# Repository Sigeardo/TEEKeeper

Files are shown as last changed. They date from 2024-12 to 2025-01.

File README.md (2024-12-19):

<p align="center">
  
</p>

**TEEKeeper** (_Temperature Environment Electronic Keeper_, or _TEEK_ for short) is an open source, Arduino based controller for high temperature electric ovens, such as heat treating ovens for metallurgy/bladesmithing, glass and ceramic kilns, etc.
In a broader sense, this projects aims to develop a platform that can be upgraded, expanded and extended by anyone, bringing more advanced control features to the users.

# Project principles
This university & passion project has been developed with 5 principles in mind:

**1) Open Source and DIY oriented design:**
     TEEK has been inspired by and made possible by many open source and DIY sources, in the forms of documentation, educational material, tools, software, designs etc.
     This project embraces these principles and aspires to give something back to these communities.

**2) Safety and Security:**
     Both in the design of the code and the circuits, developing methods & functions keeping in mind the potential risks for the user.

**3) Accessibility & ease of use:**
     The system may grow more and more complex, but the user must be presented with a simple, undestrandable and intuitive U/I.
     The code must be as readable as possible, to allow anyone to approach the codebase to make 

**4) It doesn't stop at the board:**
     Data logging and analysis tools can help to improve workflows and perform diagnostics checks. Give users data collection methods, statistics and tools.

**6) Be creative & don't be afraid of complexity!**
     But still, try to keep it simple - not trivial!
     
***DISCLAIMER: high temperature & electric related hazards are very real. 
Be aware of what you're doing and use this code at your own risk.***

<p align="center">
  
</p>

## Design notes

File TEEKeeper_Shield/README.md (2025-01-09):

# TEEKeeper Shield

<p align="center">
  
</p>

**TEEKeeper** (_Temperature Environment Electronic Keeper_, or _TEEK_ for short) is an open source, Arduino based controller for high temperature electric ovens, such as heat treating ovens for metallurgy/bladesmithing, glass and ceramic kilns, etc.
In a broader sense, this projects aims to develop a platform that can be upgraded, expanded and extended by anyone, bringing more advanced control features to the users.

This branch contains the KiCad & Gerber source files for the TEEKeeper Shield circuit. The main components are:
> [Arduino Mega2560](https://docs.arduino.cc/hardware/mega-2560/)

> [Adafruit MAX31855K temperature sensor](https://www.adafruit.com/product/269)

> SD card reader w/ 8 pin interface [(example)](https://europe1.discourse-cdn.com/arduino/original/4X/2/f/4/2f487c179e937e868c1862e275f90aaaed0d1cb2.jpeg)

> 3.5" TFT 480x320px ILI9486/HX8357 Screen Mega Shield [LCDWIKI](http://www.lcdwiki.com/3.5inch_Arduino_Display-Mega2560)

> Normally open door switch

> Rotary encoder with push button [Aliexpress](https://it.aliexpress.com/i/32920789846.html)

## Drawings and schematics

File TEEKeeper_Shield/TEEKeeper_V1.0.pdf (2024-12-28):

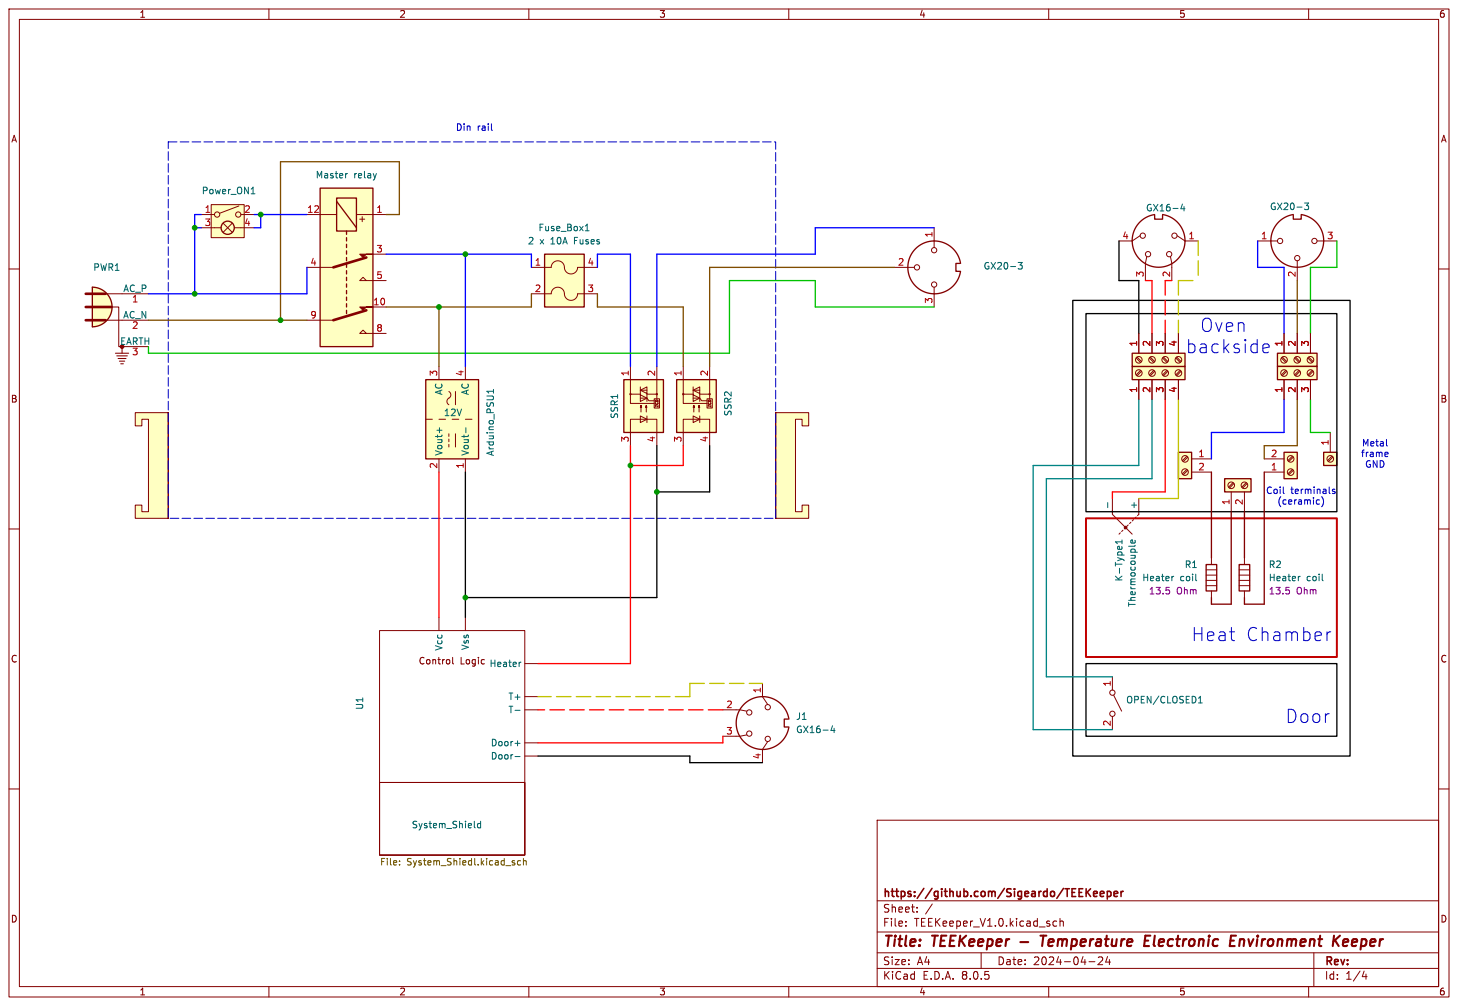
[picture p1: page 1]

-+ K-Type1 Thermocouple R2 Heater coil 13.5 Ohm

Id: 1/4 Title: TEEKeeper - Temperature Electronic Environment Keeper File: TEEKeeper_V1.0.kicad_sch Sheet: / https://github.com/Sigeardo/TEEKeeper

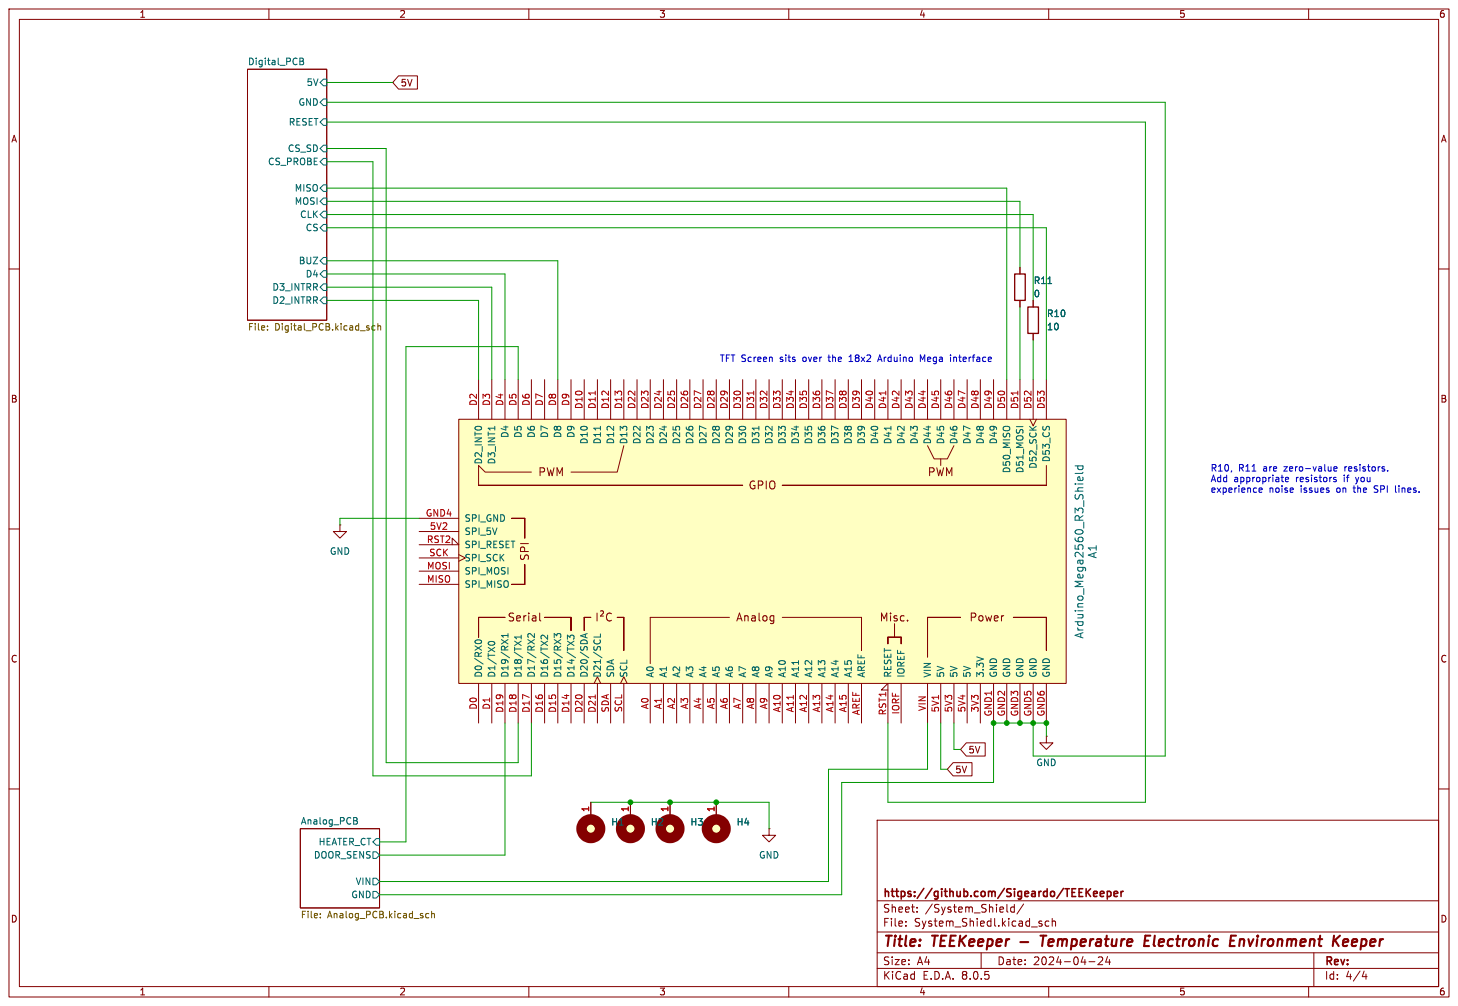
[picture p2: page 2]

1 H3 þÿI²C Analog Misc. Power PWM PWM

https://github.com/Sigeardo/TEEKeeper DOOR_SENS

Id: 4/4 Title: TEEKeeper - Temperature Electronic Environment Keeper File: System_Shiedl.kicad_sch Sheet: /System_Shield/

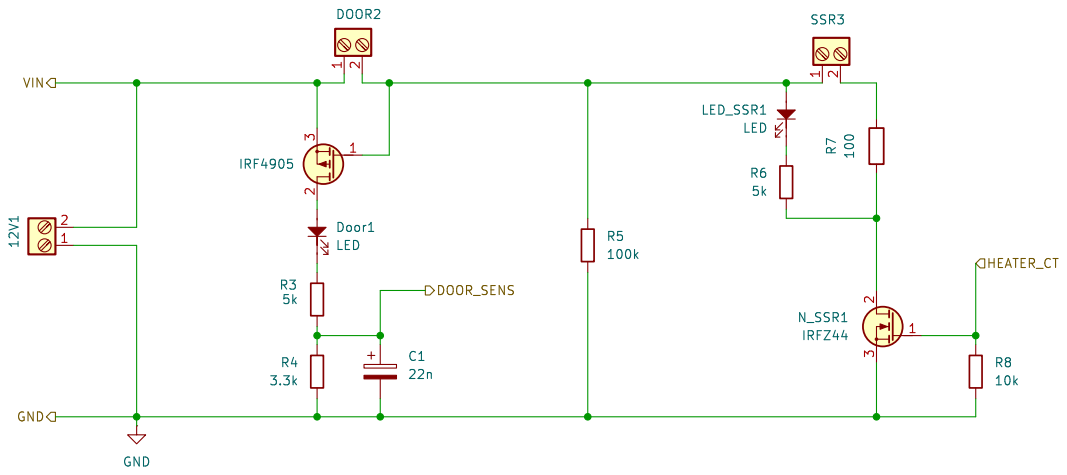
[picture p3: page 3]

https://github.com/Sigeardo/TEEKeeper
Id: 5/4 Title: TEEKeeper - Temperature Electronic Environment Keeper File: Analog_PCB.kicad_sch Sheet: /System_Shield/Analog_PCB/

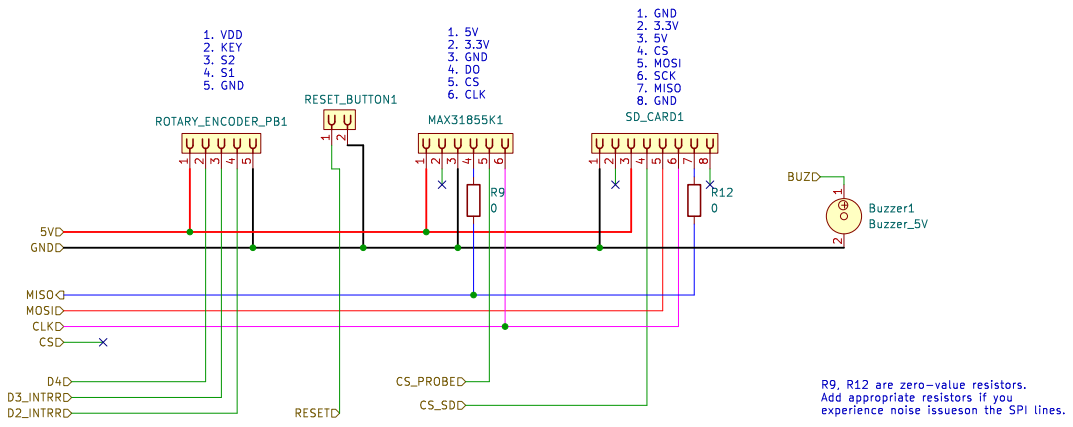
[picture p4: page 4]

https://github.com/Sigeardo/TEEKeeper
Id: 6/4 Title: TEEKeeper - Temperature Electronic Environment Keeper File: Digital_PCB.kicad_sch Sheet: /System_Shield/Digital_PCB/

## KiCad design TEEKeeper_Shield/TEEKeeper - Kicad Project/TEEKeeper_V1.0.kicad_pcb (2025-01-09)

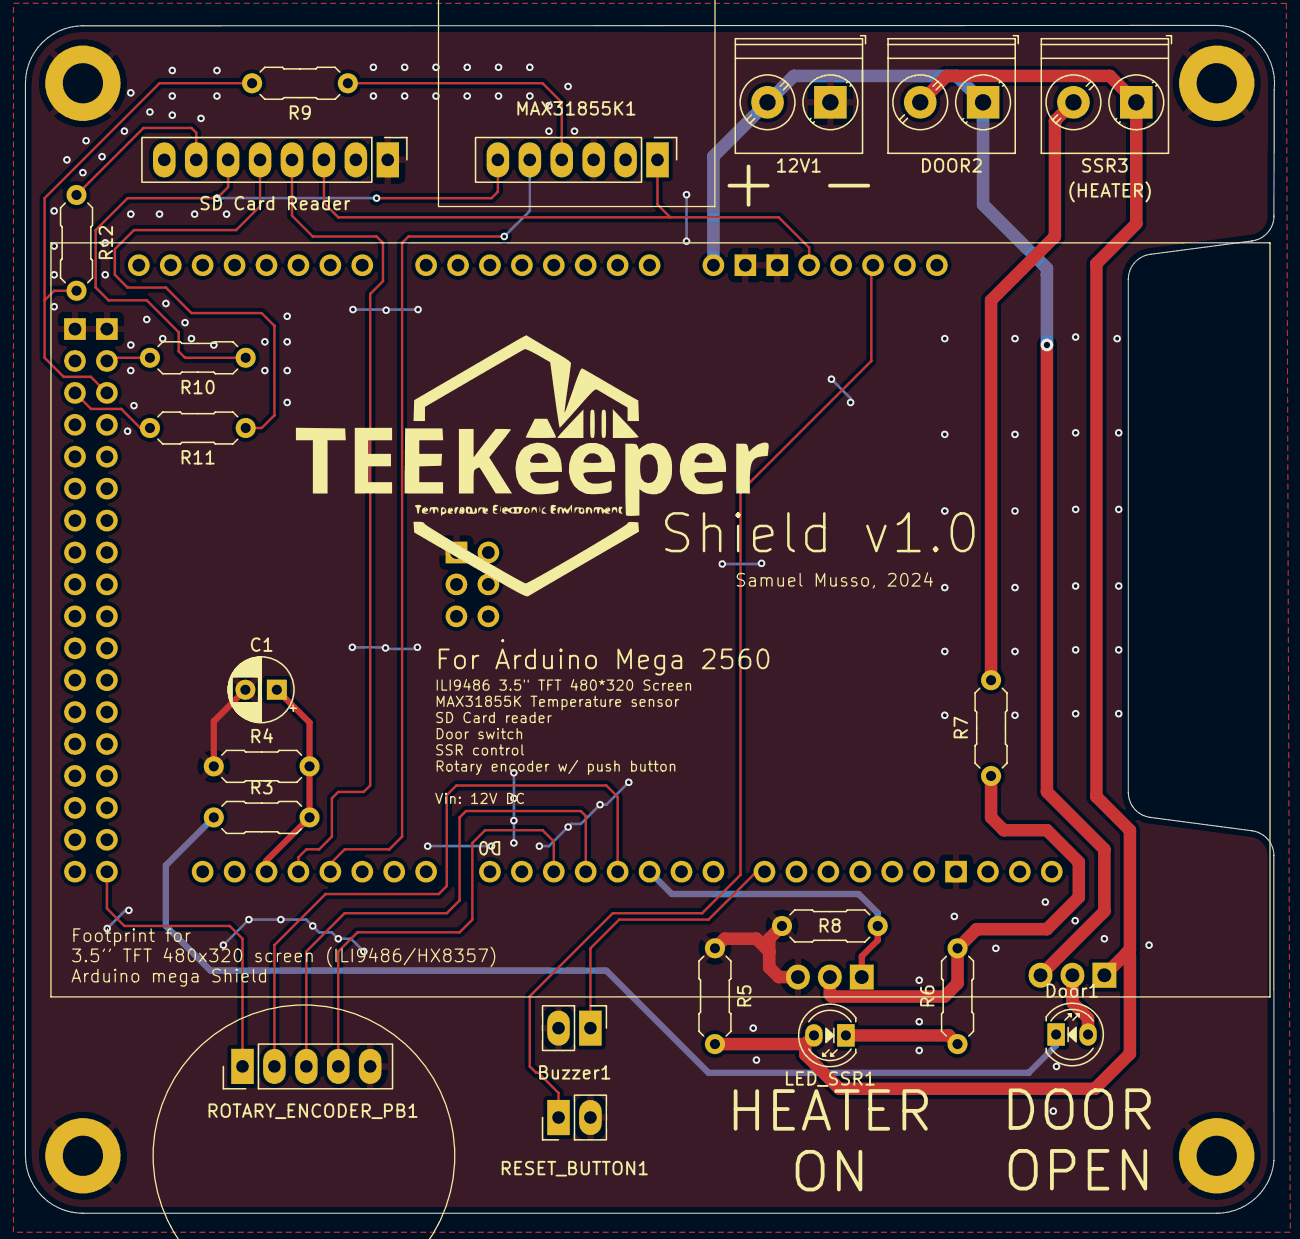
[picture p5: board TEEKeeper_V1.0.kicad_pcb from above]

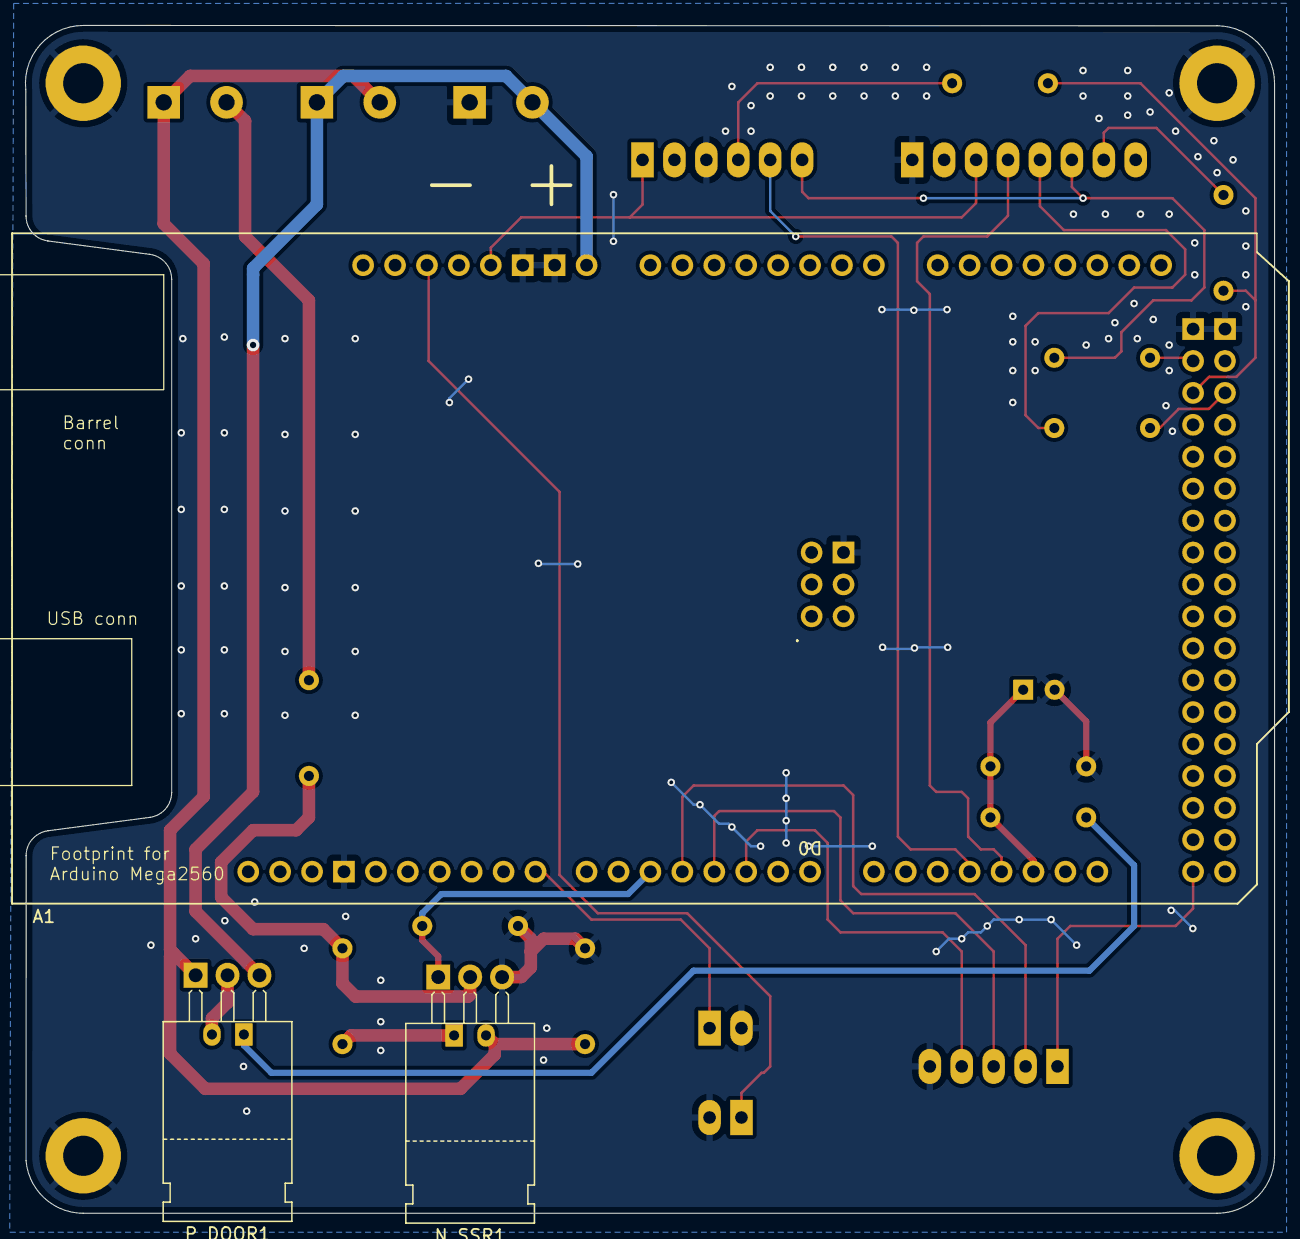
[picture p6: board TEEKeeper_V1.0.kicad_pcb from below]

Board: 2 copper layers, 99.4 x 94.5 mm, 28 parts (2 on the bottom side), 25 nets.

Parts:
12V1: Screw_Terminal_2_P5.00mm; TerminalBlock_Phoenix_PT-1,5-2-5.0-H_1x02_P5.00mm_Horizontal
A1: Arduino_Mega2560_R3_Shield
Buzzer1: Buzzer_5V; PinHeader_1x02_P2.54mm_Vertical
C1: 22n; CP_Radial_D5.0mm_P2.50mm
DOOR2: Screw_Terminal_2_P5.00mm; TerminalBlock_Phoenix_PT-1,5-2-5.0-H_1x02_P5.00mm_Horizontal
Door1: LED; LED_D4.0mm
H1, H2, H3, H4: MountingHole_M3_3.2mm_Pad; MountingHole_3.2mm_Pad
LED_SSR1: LED; LED_D4.0mm
MAX31855K1: PINHD_1x6_Female; PinSocket_1x06_P2.54mm_Vertical
N_SSR1: IRFZ44; TO-220-3_Horizontal_TabUp
P_DOOR1: IRF4905; TO-220-3_Horizontal_TabUp
R3, R6: 5k; R_Axial_DIN0207_L6.3mm_D2.5mm_P7.62mm_Horizontal
R4: 3.3k; R_Axial_DIN0207_L6.3mm_D2.5mm_P7.62mm_Horizontal
R5: 100k; R_Axial_DIN0207_L6.3mm_D2.5mm_P7.62mm_Horizontal
R7: 100; R_Axial_DIN0207_L6.3mm_D2.5mm_P7.62mm_Horizontal
R8: 10k; R_Axial_DIN0207_L6.3mm_D2.5mm_P7.62mm_Horizontal
R9, R10, R11, R12: 10; R_Axial_DIN0207_L6.3mm_D2.5mm_P7.62mm_Horizontal
RESET_BUTTON1: PINHD_1x2_Female; PinHeader_1x02_P2.54mm_Vertical
ROTARY_ENCODER_PB1: PINHD_1x5_Female; PinHeader_1x05_P2.54mm_Vertical
SD_CARD1: PINHD_1x8_Female; PinSocket_1x08_P2.54mm_Vertical
SSR3: Screw_Terminal_2_P5.00mm; TerminalBlock_Phoenix_PT-1,5-2-5.0-H_1x02_P5.00mm_Horizontal

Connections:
5V: A1.5V1 (5V), A1.5V3 (5V), MAX31855K1.1, ROTARY_ENCODER_PB1.1, SD_CARD1.3
/System_Shield/Analog_PCB/DOOR_SENS: A1.D19 (D19/RX1), C1.1, R3.2, R4.2
/System_Shield/Analog_PCB/HEATER_CT: A1.D5, N_SSR1.1 (G), R8.2
/System_Shield/Analog_PCB/VIN: 12V1.2, A1.VIN, DOOR2.1, P_DOOR1.3 (S)
/System_Shield/Digital_PCB/BUZ: A1.D8, Buzzer1.1
/System_Shield/Digital_PCB/CLK: MAX31855K1.6, R10.1, SD_CARD1.6
/System_Shield/Digital_PCB/CS_PROBE: A1.D17 (D17/RX2), MAX31855K1.5
/System_Shield/Digital_PCB/CS_SD: A1.D18 (D18/TX1), SD_CARD1.4
/System_Shield/Digital_PCB/D2_INTRR: A1.D2 (D2_INT0), ROTARY_ENCODER_PB1.4
/System_Shield/Digital_PCB/D3_INTRR: A1.D3 (D3_INT1), ROTARY_ENCODER_PB1.3
/System_Shield/Digital_PCB/D4: A1.D4, ROTARY_ENCODER_PB1.2
/System_Shield/Digital_PCB/MISO: A1.D50 (D50_MISO), R9.2, R12.2
/System_Shield/Digital_PCB/MOSI: R11.1, SD_CARD1.5
/System_Shield/Digital_PCB/RESET: A1.RST1 (RESET), RESET_BUTTON1.1
GND: 12V1.1, A1.GND1 (GND), A1.GND2 (GND), A1.GND3 (GND), A1.GND4 (SPI_GND), A1.GND5 (GND), A1.GND6 (GND), Buzzer1.2, C1.2, H1.1, H2.1, H3.1, H4.1, MAX31855K1.3, N_SSR1.3 (S), R4.1, R5.1, R8.1, RESET_BUTTON1.2, ROTARY_ENCODER_PB1.5, SD_CARD1.1
unnamed: A1.D51 (D51_MOSI), R11.2
unnamed: A1.D52 (D52_SCK), R10.2
unnamed: Door1.1, R3.1
unnamed: LED_SSR1.1, R6.1
unnamed: MAX31855K1.4, R9.1
unnamed: N_SSR1.2 (D), R6.2, R7.1
unnamed: Door1.2, P_DOOR1.2 (D)
unnamed: DOOR2.2, LED_SSR1.2, P_DOOR1.1 (G), R5.2, SSR3.1
unnamed: R7.2, SSR3.2
unnamed: R12.1, SD_CARD1.7

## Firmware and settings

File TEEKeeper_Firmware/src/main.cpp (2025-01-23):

#include "TEEKeeper.h"
#include <arduino.h>

// == I/O 
ClickEncoder __encoder(PIN_ENCODER_S1, PIN_ENCODER_S2, PIN_ENCODER_KEY, ENCODER_STEPS); // Rotary encoder
TFT_HX8357 __screen; // TFT screen

// == TEEKeeper components
ProgramManager      __program;          // Program manager
TemperatureProbe    __probe;            // Temperature sensor
CoreSystem          __core(__probe);    // Core system
SdFat               __sd;               // SD card 
AutotuneParameters  __autPar;           // Autotune parameters wrapper
extern ScreenManager __GUI;            // Screen manager

// == Global variables
char errorStreamChar[ERROR_BUFF_SIZE]; // Error message buffer
char messageStream[ERROR_BUFF_SIZE];   // Message buffer

void setup(){
    TEEK_Setup(); // Setup & initialize the system

    #ifdef SERIAL_COMMS
        Serial.begin(9600); // Initialize the serial communication
    #endif 



    drawBaseScreen(__screen); // Draw the base screen

    __core.ReadTemperature(); // Read the temperature

    __GUI.renderCurrent(__screen); // Render the main menu screen
};

void loop(){

    __core.update(__program);                           // PWM cycle manager
    manageSystemState(__core, __program, __probe);      // Program execution manager
    __GUI.updateGraphics(__core, __screen, __encoder);  // Update the GUI
    delay(1);
};  

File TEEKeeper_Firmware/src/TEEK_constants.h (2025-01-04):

#ifndef TEEK_CONSTANTS_H
#define TEEK_CONSTANTS_H

// ===== System Constants ===============================================

#define ERROR_BUFF_SIZE 80 // size of the error message buffer

// Time is expressed in milliseconds, unless otherwise stated
#define SECOND 1000
#define MINUTE SECOND * 60

// Time limits are expressed in milliseconds
#define MAX_TIME_DOOR_OPEN 5 * MINUTE * SECOND
#define MAX_HOLD_TIME 30 * MINUTE * SECOND
#define MAX_TIME_BETWEEN_TEMP_CHECKS 1 * SECOND

// Temperature limits are defined in celsius and converted later
#define MAX_TEMP_ERROR 2            // Max error for stability
#define MAX_TEMPERATURE 1100        // Max input temperature
#define MIN_TEMPERATURE 0           // Min input temperature
#define ERROR_TEMP 1200             // Upper temperature to trigger error
#define MIN_STABLE_CYCLES 10        // Number of PWM cycles to consider the temperature stable
#define POLL_PROBE_INTERVAL 5000    // Polling interval for temp reading when not firing


// PWM cycle time
#define CYCLE_TIME 5 * SECOND

// Maximum number of allowed consecutives temperature reading errors
// before considering the temperature probe faulty and stop the system
#define MAX_N_ERROR_READINGS 10

// Placeholder values for untuned systems
// TODO find a SIMPLE way to eyeball the default values from
// TODO the system characteristics (outside this code)
// TODO like a spreadsheet idk 
// TODO or a simple python script
// TODO no matlab simulink or other fancy stuff
#define PWM_DEFAULT_KP 0.4
#define PWM_DEFAULT_KI 0.5
#define PWM_DEFAULT_KD 0.2

// Encoder steps per click
#define ENCODER_STEPS 4


// Memory addresses for EEPROM
// nomen est omen
#define EEPROM_ADDR_KP 0
#define EEPROM_ADDR_KI EEPROM_ADDR_KP + sizeof(double)
#define EEPROM_ADDR_KD EEPROM_ADDR_KP + 2*sizeof(double)
#define EEPROM_DEFAULT_UNIT EEPROM_KP + 3*sizeof(double)

// Autotune parameters 
#define TARGET_TEMP_FOR_AUTOTUNE 800  // Target setpoint
#define MIN_TEMP_ERROR 1              // Min deviation to count as stable
#define AUTOTUNE_TIMEOUT (unsigned long) 120*SECOND*60   // 2h timeout for tuning
#define PID_N_OSCILLATIONS 10         // Number of oscillations required for tuning


// ===== GRAPHICS ========
#define MIN_TIME_BETWEEN_SCREEN_UPDATES 3000 //  [ms]
#define MAX_FILES 30            // max number of files fetched from the sd card

// ====== FILES =========== 
#define MAX_INSTRUCTIONS_PER_PROGRAM 20 // Maximum number of instructions in a program
#define MAX_FILENAME_LENGTH 50          // max length of a filename
#define MAX_FILES_ON_SCREEN 5           // max number of files displayed on the screen 
#define MAX_INSTR_NAME_LENGHT 30        // max length of an instruction name

// ===== SERIAL =====
// comment out to disable serial communications
#define SERIAL_COMMS


#endif

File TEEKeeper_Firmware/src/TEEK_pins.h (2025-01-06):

#ifndef TEEK_PINS_H
#define TEEK_PINS_H


// ===== System PINS ==================================================


// Board
#define SYSTEM_ARDUINO_MEGA 
//#define SYSTEN_ARDUINO_UNO

// === SPI interface
#ifdef SYSTEM_ARDUINO_MEGA
    // Arduino MEGA 2560 SPI interface
    #define PIN_SPI_MISO 50
    #define PIN_SPI_MOSI 51
    #define PIN_SPI_CLK 52
    #define PIN_SPI_SS 53
#endif

// for debugging purpouses only
#ifdef SYSTEM_ARDUINO_UNO
// Arduino UNO SPI interface
#define PIN_SPI_MISO 12
#define PIN_SPI_MOSI 11
#define PIN_SPI_CLK 13
#define PIN_SPI_SS 10
#endif


// == MAX31855 Select pin
#define PIN_PROBE_CS 17

// == SD Card PINS
#define PIN_SD_CS 18

// == Door interrupt pin
#define PIN_DOOR_INTERRUPT 19

// == Encoder PINS
#define PIN_ENCODER_S1  2
#define PIN_ENCODER_S2  3
#define PIN_ENCODER_KEY 4

// Heater control pin
#define PIN_HEATER 5

#endif

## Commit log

2024-12-06 Added Kicad and Gerber files
    [Analog_PCB.kicad_sch, Digital_PCB.kicad_sch, System_Shiedl.kicad_sch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]
2024-12-19 Resolved minor issues
    Fixed broken / bad designed reference connections, fixed pcb courtyard and edges, general cleanup
    [Analog_PCB.kicad_sch, Digital_PCB.kicad_sch, System_Shiedl.kicad_sch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]
2024-12-19 Minor footprint fixes
    Changed LED footprints for better accomodate the devices I've been using.
    Fixed some edge cuts issues and refilled zones.
    [TEEKeeper_V1.0-B_Cu.gbr, TEEKeeper_V1.0-B_Mask.gbr, TEEKeeper_V1.0-B_Paste.gbr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]
2024-12-28 Minor changes
    [Digital_PCB.kicad_sch, System_Shiedl.kicad_sch, TEEKeeper_V1.0.kicad_pcb]
2025-01-03 Added connector cutouts
    Added cutouts for the Arduino Mega barrel and USB-A connector.
    Rerouted connections accordingly.
    Added more vias to GND plane along SPI lines and other parallel strips.
    Added clearance for some components.
    [TEEKeeper_V1.0.kicad_pcb]
2025-01-03 Updated gerber files
    [TEEKeeper_V1.0-B_Cu.gbr, TEEKeeper_V1.0-B_Mask.gbr, TEEKeeper_V1.0-B_Paste.gbr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]
2025-01-05 updated schematics
    [Analog_PCB.kicad_sch, Digital_PCB.kicad_sch, System_Shiedl.kicad_sch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]
2025-01-06 Solved spi hanging issue
    [TEEK_dataStructures.cpp, TEEK_dataStructures.h, TEEK_pins.h]
2025-01-07 Updated the ReadTemperature() method to handle critical errors
    [TEEK_dataStructures.cpp, TEEK_dataStructures.h, TEEKeeper.cpp]
2025-01-08 fixed Critical Error Screen displaying
    [TEEK_dataStructures.cpp, TEEK_graphics.cpp, TEEK_graphics.h]
2025-01-09 Reworked Arduino Mega clearance
    Due to some clones having their USB and barrel connector placed in slightly different locations, added a big cutout and rerouted tracks accordingly
    uniformed 12V copper lines width
    [TEEKeeper_V1.0-B_Cu.gbr, TEEKeeper_V1.0-B_Mask.gbr, TEEKeeper_V1.0-B_Paste.gbr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]
2025-01-23 re-added probe debug mock function
